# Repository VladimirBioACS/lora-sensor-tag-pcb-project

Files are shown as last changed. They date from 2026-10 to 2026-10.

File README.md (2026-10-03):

# LoRa Sensor TAG

Simple LoRa humidity and temperature monitoring device, based on the ESP32-Wroom-D SoC module.
Repo contains KiCAD 10 project for LoRa Sensor TAG device with external component libs.

## Project description

The architecture of the project is described with the diagram below (lora_sensor_tag_architecture.jpg):

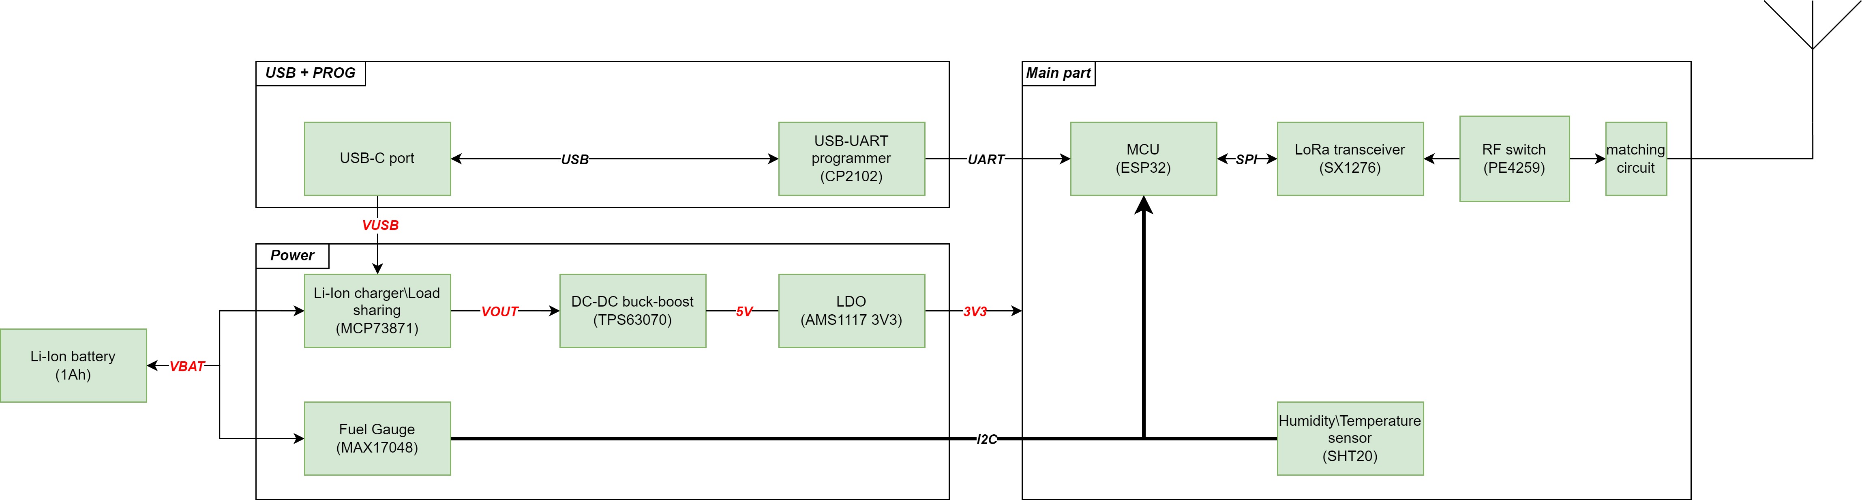
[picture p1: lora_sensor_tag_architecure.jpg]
project architecure


The LoRa Sensor Project is designed to create a network of low-power, long-range sensors for environmental monitoring. 
The project aims to leverage LoRa technology to enable efficient data collection from remote locations, 
providing real-time insights into various environmental parameters such as temperature and humidity. The LoRa modem works
within 433 Mhz LF baseband.

It is developed simply for the educational purpose, aiming to provide students and hobbyists with hands-on experience in 
building and managing a LoRa-based sensor network.

The device composed of several key components:

- A LoRa module for long-range wireless communication.
- Sensor for measuring environmental parameters such as temperature and humidity.
- A microcontroller to process sensor data and manage communication.
- A power source (li-ion battery) with DC-DC buck-boost converter and LDO to manage power supply and ensure stable operation.
- Auxiliary components such as USB-UART bridge for serial communication and programming the microcontroller.

The following key components were used:

- MAX17048G_T10 - Fuel Gauge IC to monitor battery status
- MCP73871-2CAI_ML - Li-Ion/Li-Polymer Battery Charger to manage battery charging and protection
- SHT20 - Temperature and Humidity Sensor to measure environmental conditions
- SX1276IMLTRT - LoRa Transceiver Module to enable long-range wireless communication
- PE4259 - RF switch for LoRa antenna
- TPS63070RNMR - Buck-Boost Converter to manage power supply and ensure stable operation
- ESP32 - Microcontroller to process sensor data and manage communication
- CP2102 - USB to UART Bridge Controller to enable serial communication between the microcontroller and a computer. Also, acts as a programmer for the microcontroller.

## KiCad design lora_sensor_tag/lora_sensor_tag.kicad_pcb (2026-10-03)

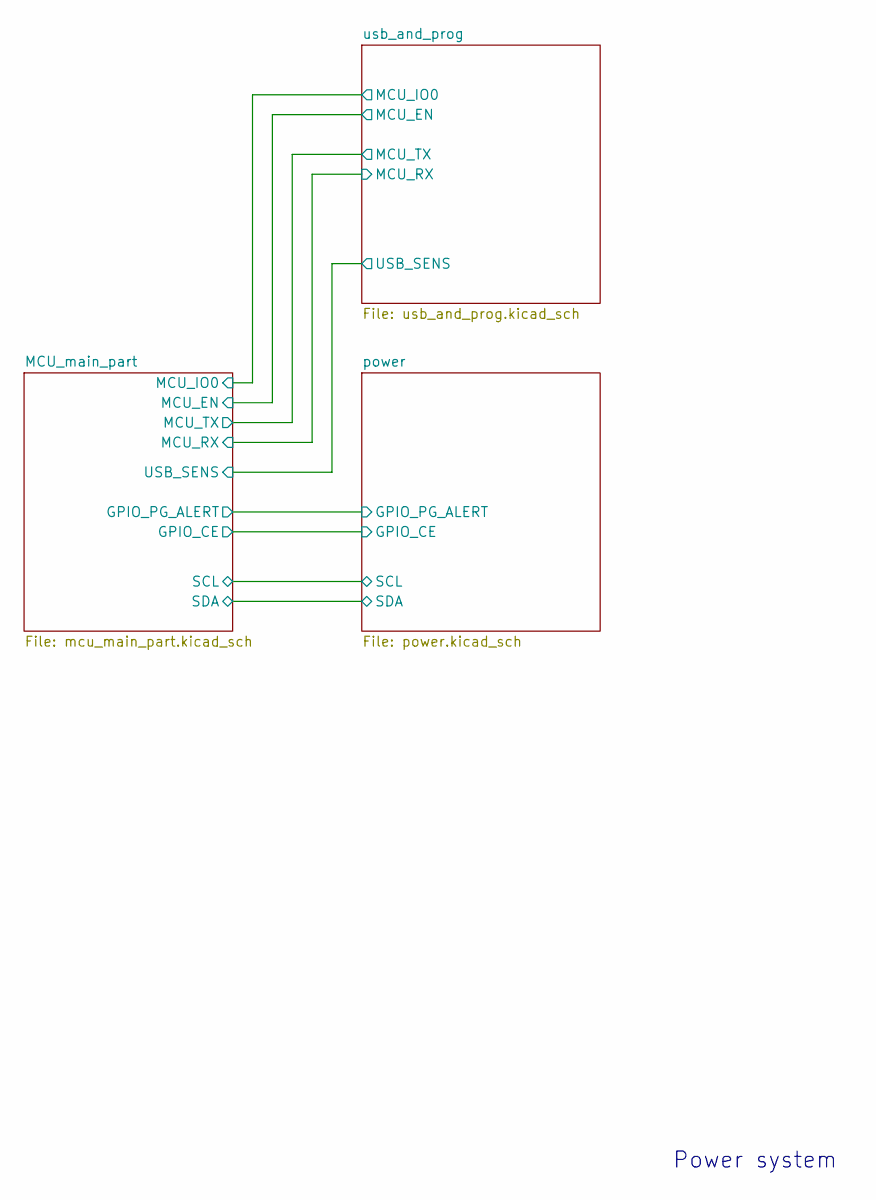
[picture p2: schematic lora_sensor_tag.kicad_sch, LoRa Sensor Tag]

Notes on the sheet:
Power system

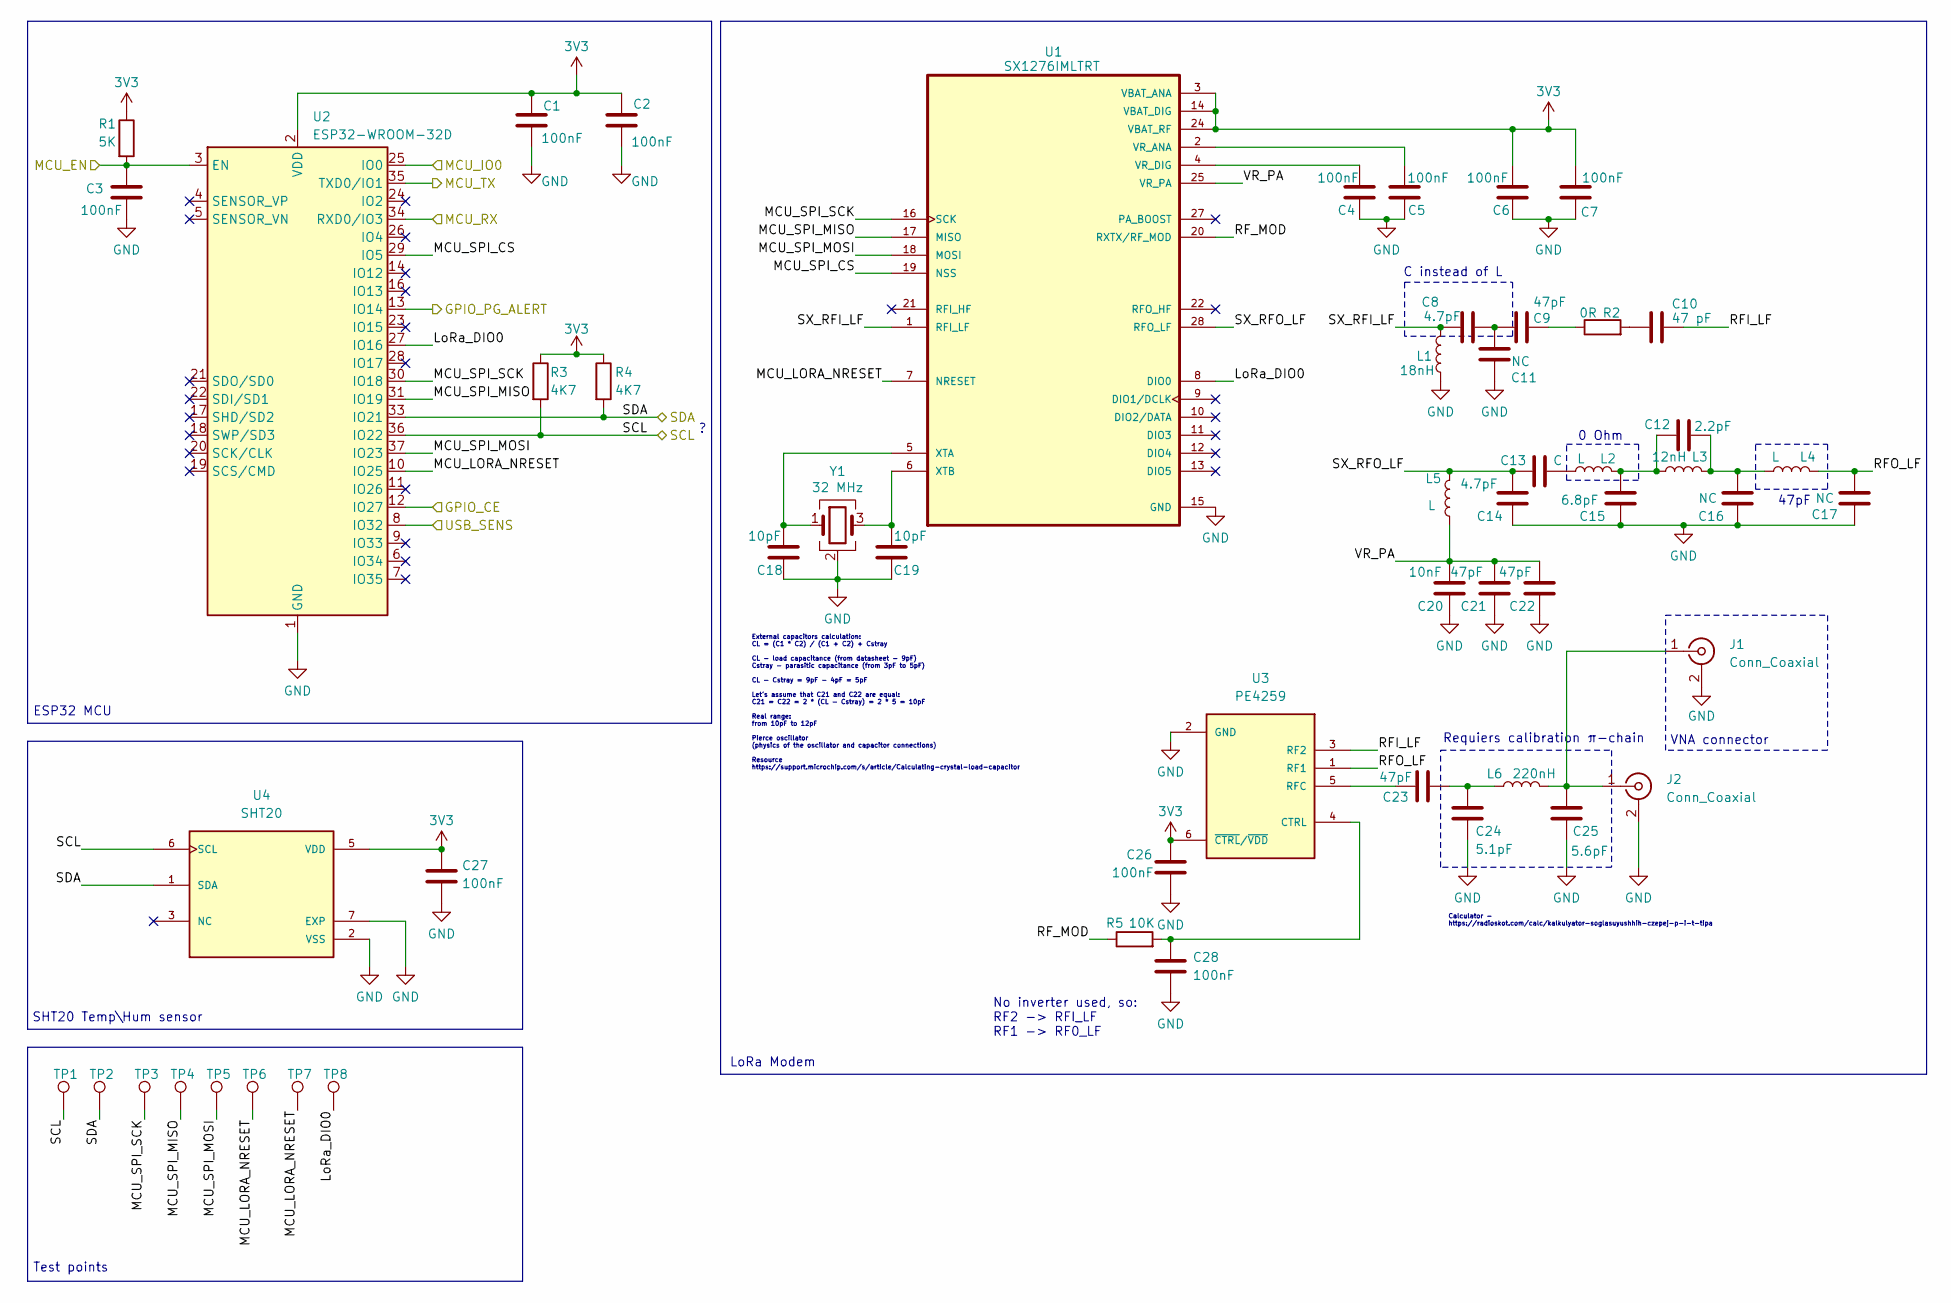
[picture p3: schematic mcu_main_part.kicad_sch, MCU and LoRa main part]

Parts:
C1, C2, C3, C4, C5, C6, C7, C26, C27, C28: 100nF; C_0603_1608Metric
C8, C14: 4.7pF; C_0402_1005Metric
C9, C21, C22, C23: 47pF; C_0402_1005Metric
C10: 47 pF; C_0402_1005Metric
C11, C16, C17: NC; C_0402_1005Metric
C12: 2.2pF; C_0402_1005Metric
C13: C; C_0402_1005Metric
C15: 6.8pF; C_0402_1005Metric
C18, C19: 10pF; C_0603_1608Metric
C20: 10nF; C_0402_1005Metric
C24: 5.1pF; C_0402_1005Metric
C25: 5.6pF; C_0402_1005Metric
J1, J2: Conn_Coaxial; SMA_BAT_Wireless_BWSMA-KWE-Z001
L1: 18nH; L_0402_1005Metric
L2: L; R_0402_1005Metric
L3: 12nH; L_0402_1005Metric
L4: L; C_0402_1005Metric
L5: L; L_0402_1005Metric
L6: 220nH; L_0402_1005Metric
R1: 5K; R_0603_1608Metric
R2: 0R; VREG_TPS63070RNMR
R3, R4: 4K7; R_0603_1608Metric
R5: 10K; R_0603_1608Metric
TP1, TP2, TP3, TP4, TP5, TP6, TP7, TP8: TestPoint; TestPoint_Pad_D1.0mm
U1: SX1276IMLTRT; QFN65P600X600X100-29N; PARTREV 5
U2: ESP32-WROOM-32D
U3: PE4259; SOT65P215X110-6N
U4: SHT20; XDCR_SHT20; PARTREV 4
Y1: 32 MHz; Crystal_SMD_3225-4Pin_3.2x2.5mm

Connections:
3V3: C1.1, C2.1, C6.1, C7.1, C26.1, C27.1, R1.1, R3.1, R4.1, U1.3 (VBAT_ANA), U1.14 (VBAT_DIG), U1.24 (VBAT_RF), U2.2 (VDD), U3.6 (~CTRL/~VDD), U4.5 (VDD); also elsewhere on the board
/MCU_main_part/GPIO_CE: U2.12 (IO27); also elsewhere on the board
/MCU_main_part/GPIO_PG_ALERT: U2.13 (IO14); also elsewhere on the board
/MCU_main_part/LoRa_DIO0: TP8.1 (1_1), U1.8 (DIO0), U2.27 (IO16)
/MCU_main_part/MCU_EN: C3.1, R1.2, U2.3 (EN); also elsewhere on the board
/MCU_main_part/MCU_IO0: U2.25 (IO0); also elsewhere on the board
/MCU_main_part/MCU_LORA_NRESET: TP6.1 (1_1), TP7.1 (1_1), U1.7 (NRESET), U2.10 (IO25)
/MCU_main_part/MCU_RX: U2.34 (RXD0/IO3); also elsewhere on the board
/MCU_main_part/MCU_SPI_CS: U1.19 (NSS), U2.29 (IO5)
/MCU_main_part/MCU_SPI_MISO: TP4.1 (1_1), U1.17 (MISO), U2.31 (IO19)
/MCU_main_part/MCU_SPI_MOSI: TP5.1 (1_1), U1.18 (MOSI), U2.37 (IO23)
/MCU_main_part/MCU_SPI_SCK: TP3.1 (1_1), U1.16 (SCK), U2.30 (IO18)
/MCU_main_part/MCU_TX: U2.35 (TXD0/IO1); also elsewhere on the board
/MCU_main_part/RFI_LF: C10.2, U3.3 (RF2)
/MCU_main_part/RFO_LF: C17.1, L4.2, U3.1 (RF1)
/MCU_main_part/RF_MOD: R5.1, U1.20 (RXTX/RF_MOD)
/MCU_main_part/SCL: R3.2, TP1.1 (1_1), U2.36 (IO22), U4.6 (SCL); also elsewhere on the board
/MCU_main_part/SDA: R4.2, TP2.1 (1_1), U2.33 (IO21), U4.1 (SDA); also elsewhere on the board
/MCU_main_part/SX_RFI_LF: C8.1, L1.2, U1.1 (RFI_LF)
/MCU_main_part/SX_RFO_LF: C13.2, C14.1, L5.2, U1.28 (RFO_LF)
/MCU_main_part/USB_SENS: U2.8 (IO32); also elsewhere on the board
/MCU_main_part/VR_PA: C20.1, C21.1, C22.1, L5.1, U1.25 (VR_PA)
GND: C1.2, C2.2, C3.2, C4.2, C5.2, C6.2, C7.2, C11.2, C14.2, C15.2, C16.2, C17.2, C18.2, C19.2, C20.2, C21.2, C22.2, C24.1, C25.1, C26.2, C27.2, C28.1, J1.2 (Ext), J2.2 (Ext), L1.1, U1.15 (GND), U1.23 (GND), U1.26 (GND), U1.29 (GND), U2.1 (GND), U2.15 (GND), U2.38 (GND), U2.39 (GND), U3.2 (GND), U4.2 (VSS), U4.7 (EXP), Y1.2 (G), Y1.4 (G); also elsewhere on the board
unnamed: C9.2, R2.1
unnamed: C10.1, R2.2
unnamed: C8.2, C9.1, C11.1
unnamed: C12.1, C16.1, L3.2, L4.1
unnamed: C12.2, C15.1, L2.2, L3.1
unnamed: C13.1, L2.1
unnamed: C23.2, C24.2, L6.1
unnamed: C25.2, J1.1 (In), J2.1 (In), L6.2
unnamed: C5.1, U1.2 (VR_ANA)
unnamed: C4.1, U1.4 (VR_DIG)
unnamed: C18.1, U1.5 (XTA), Y1.1
unnamed: C19.1, U1.6 (XTB), Y1.3
unnamed: C28.2, R5.2, U3.4 (CTRL)
unnamed: C23.1, U3.5 (RFC)

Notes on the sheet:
SHT20 Temp\Hum sensor
External capacitors calculation: CL = (C1 * C2) / (C1 + C2) + Cstray CL - load capacitance (from datasheet - 9pF) Cstray - parasitic capacitance (from 3pF to 5pF) CL - Cstray = 9pF - 4pF = 5pF Let's assume that C21 and C22 are equal: C21 = C22 = 2 * (CL - Cstray) = 2 * 5 = 10pF Real range: from 10p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
Requiers calibration π-chain
Test points
LoRa Modem
ESP32 MCU
0 Ohm
47pF
VNA connector
C instead of L
Calculator - https://radioskot.com/calc/kalkulyator-soglasuyushhih-czepej-p-i-t-tipa
No inverter used, so: RF2 -> RFI_LF RF1 -> RF0_LF

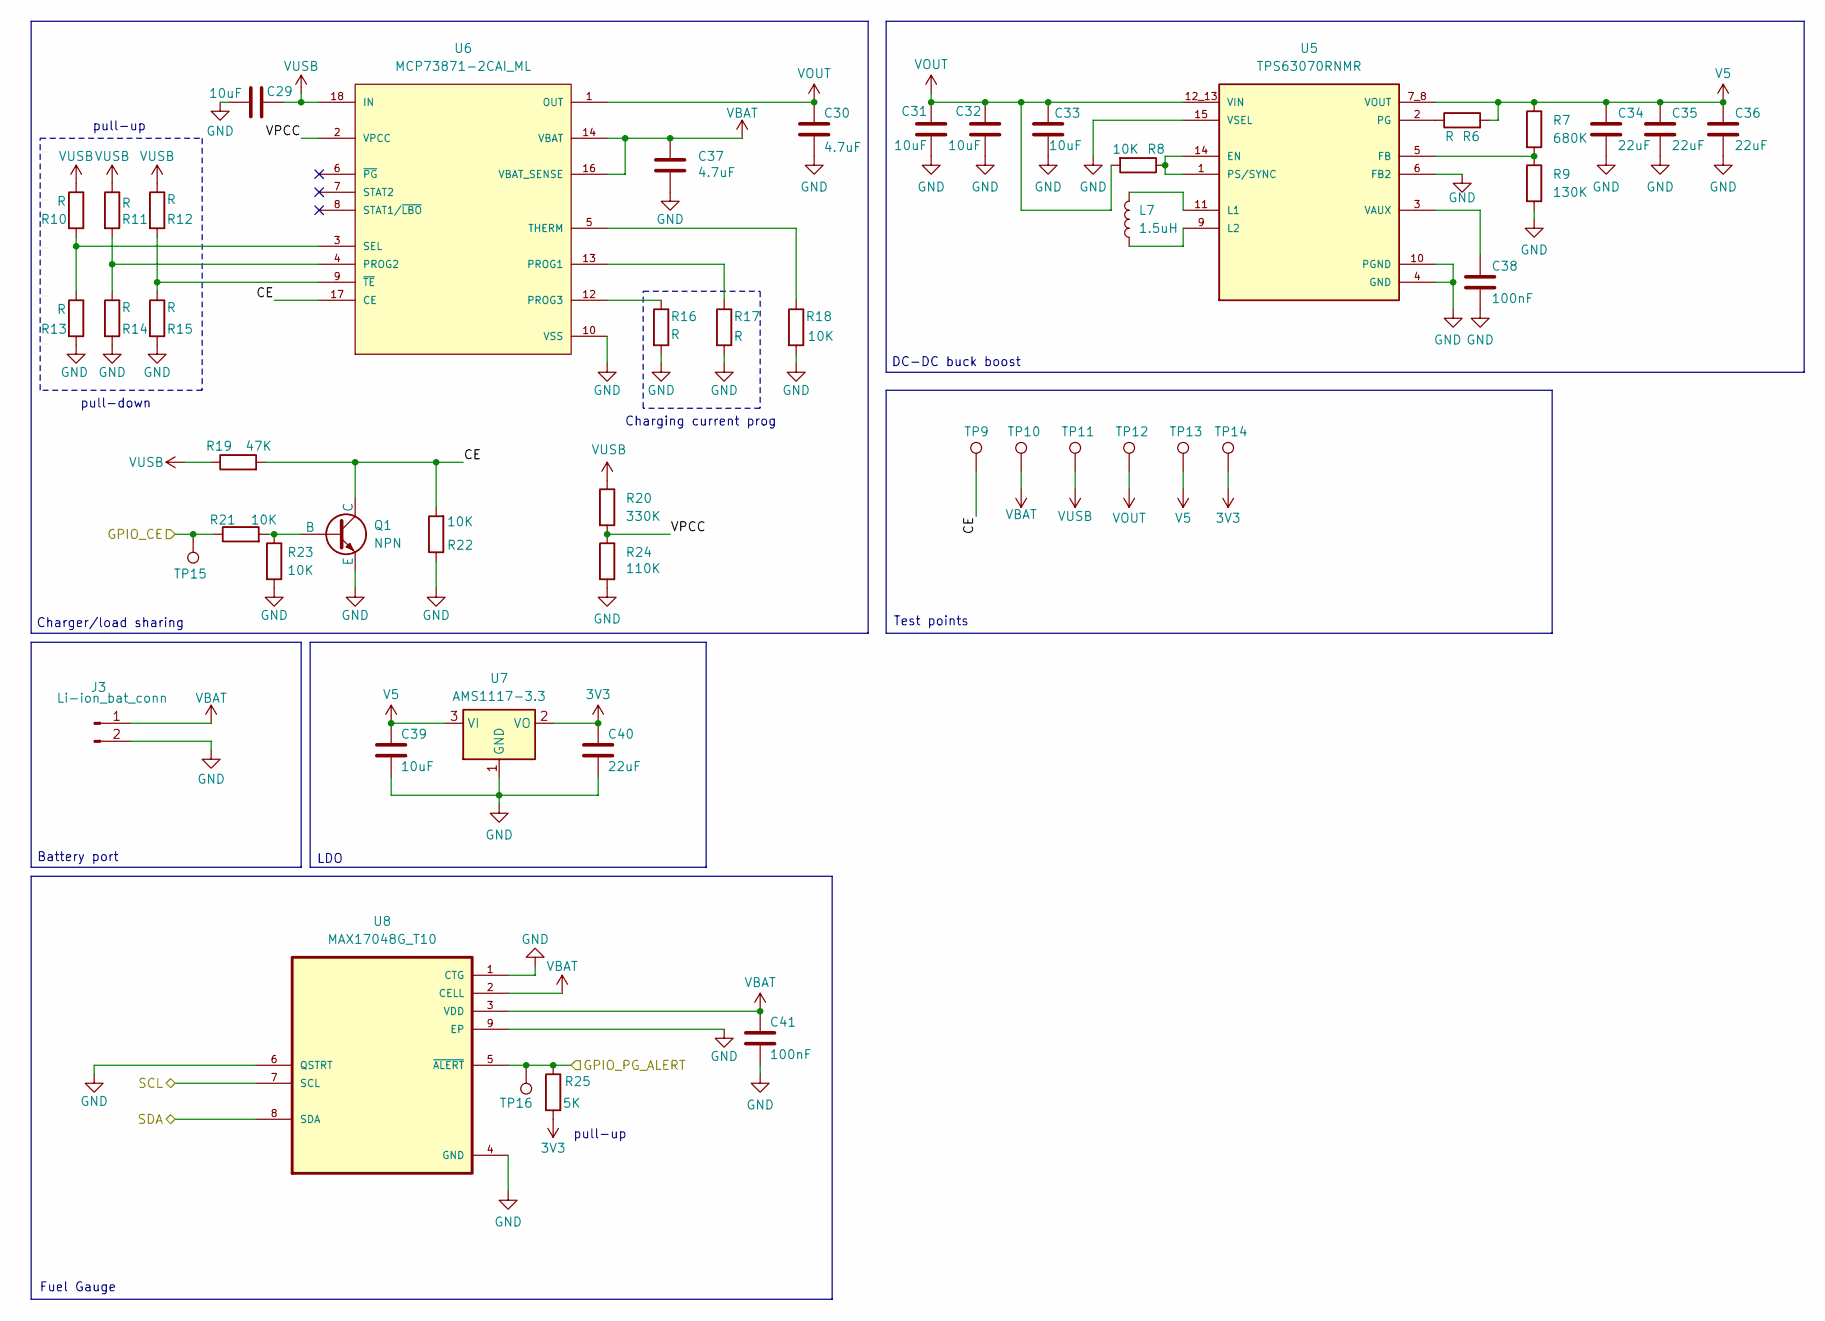
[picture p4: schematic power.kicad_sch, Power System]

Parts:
C29, C33, C39: 10uF; C_0603_1608Metric
C30, C37: 4.7uF; C_0603_1608Metric
C31, C32: 10uF; C_0805_2012Metric
C34, C35, C36: 22uF; C_0805_2012Metric
C38, C41: 100nF; C_0603_1608Metric
C40: 22uF; C_0603_1608Metric
J3: Li-ion_bat_conn; PinHeader_1x02_P2.54mm_Vertical
L7: 1.5uH; L_Coilcraft_XxL4040
Q1: NPN; SOT-23
R6, R10, R11, R12, R13, R14, R15, R16, R17: R; R_0603_1608Metric
R7: 680K; R_0603_1608Metric
R8, R18, R21, R22, R23: 10K; R_0603_1608Metric
R9: 130K; R_0603_1608Metric
R19: 47K; R_0603_1608Metric
R20: 330K; R_0603_1608Metric
R24: 110K; R_0603_1608Metric
R25: 5K; R_0603_1608Metric
TP9, TP10, TP11, TP12, TP13, TP14, TP15, TP16: TestPoint; TestPoint_Pad_D1.0mm
U5: TPS63070RNMR; VREG_TPS63070RNMR; PARTREV B
U6: MCP73871-2CAI_ML; QFN50P400X400X100-21N; PARTREV D
U7: AMS1117-3.3; SOT-223-3_TabPin2
U8: MAX17048G_T10; SON50P200X200X80-9N

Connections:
3V3: C40.1, R25.2, TP14.1 (1_1), U7.2 (VO); also elsewhere on the board
/MCU_main_part/GPIO_CE: R21.1, TP15.1 (1_1); also elsewhere on the board
/MCU_main_part/GPIO_PG_ALERT: R25.1, TP16.1 (1_1), U8.5 (~ALERT); also elsewhere on the board
/MCU_main_part/SCL: U8.7 (SCL); also elsewhere on the board
/MCU_main_part/SDA: U8.8 (SDA); also elsewhere on the board
/power/CE: Q1.1 (C), R19.2, R22.2, TP9.1 (1_1), U6.17 (CE)
/power/VPCC: R20.2, R24.1, U6.2 (VPCC)
GND: C29.1, C30.2, C31.2, C32.2, C33.2, C34.2, C35.2, C36.2, C37.2, C38.2, C39.2, C40.2, C41.2, J3.2, Q1.3 (E), R9.2, R13.2, R14.2, R15.2, R16.2, R17.2, R18.2, R22.1, R23.2, R24.2, U5.4 (GND), U5.6 (FB2), U5.10 (PGND), U5.15 (VSEL), U6.10 (VSS), U6.11 (VSS), U6.21 (VSS), U7.1 (GND), U8.1 (CTG), U8.4 (GND), U8.6 (QSTRT), U8.9 (EP); also elsewhere on the board
unnamed: Q1.2 (B), R21.2, R23.1
unnamed: R8.1, U5.1 (PS/SYNC), U5.14 (EN)
unnamed: R7.2, R9.1, U5.5 (FB)
unnamed: L7.2, U5.11 (L1)
unnamed: L7.1, U5.9 (L2)
unnamed: R6.1, U5.2 (PG)
unnamed: C38.1, U5.3 (VAUX)
unnamed: R17.1, U6.13 (PROG1)
unnamed: R11.2, R14.1, U6.4 (PROG2)
unnamed: R16.1, U6.12 (PROG3)
unnamed: R10.2, R13.1, U6.3 (SEL)
unnamed: R18.1, U6.5 (THERM)
unnamed: R12.2, R15.1, U6.9 (~TE)
V5: C34.1, C35.1, C36.1, C39.1, R6.2, R7.1, TP13.1 (1_1), U5.7_8 (VOUT), U7.3 (VI)
VBAT: C37.1, C41.1, J3.1, TP10.1 (1_1), U6.14 (VBAT), U6.15 (VBAT), U6.16 (VBAT_SENSE), U8.2 (CELL), U8.3 (VDD)
VOUT: C30.1, C31.1, C32.1, C33.1, R8.2, TP12.1 (1_1), U5.12_13 (VIN), U6.1 (OUT), U6.20 (OUT)
VUSB: C29.2, R10.1, R11.1, R12.1, R19.1, R20.1, TP11.1 (1_1), U6.18 (IN), U6.19 (IN); also elsewhere on the board

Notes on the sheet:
Charging current prog
pull-down
DC-DC buck boost
pull-up
LDO
Test points
Charger/load sharing
Battery port
Fuel Gauge

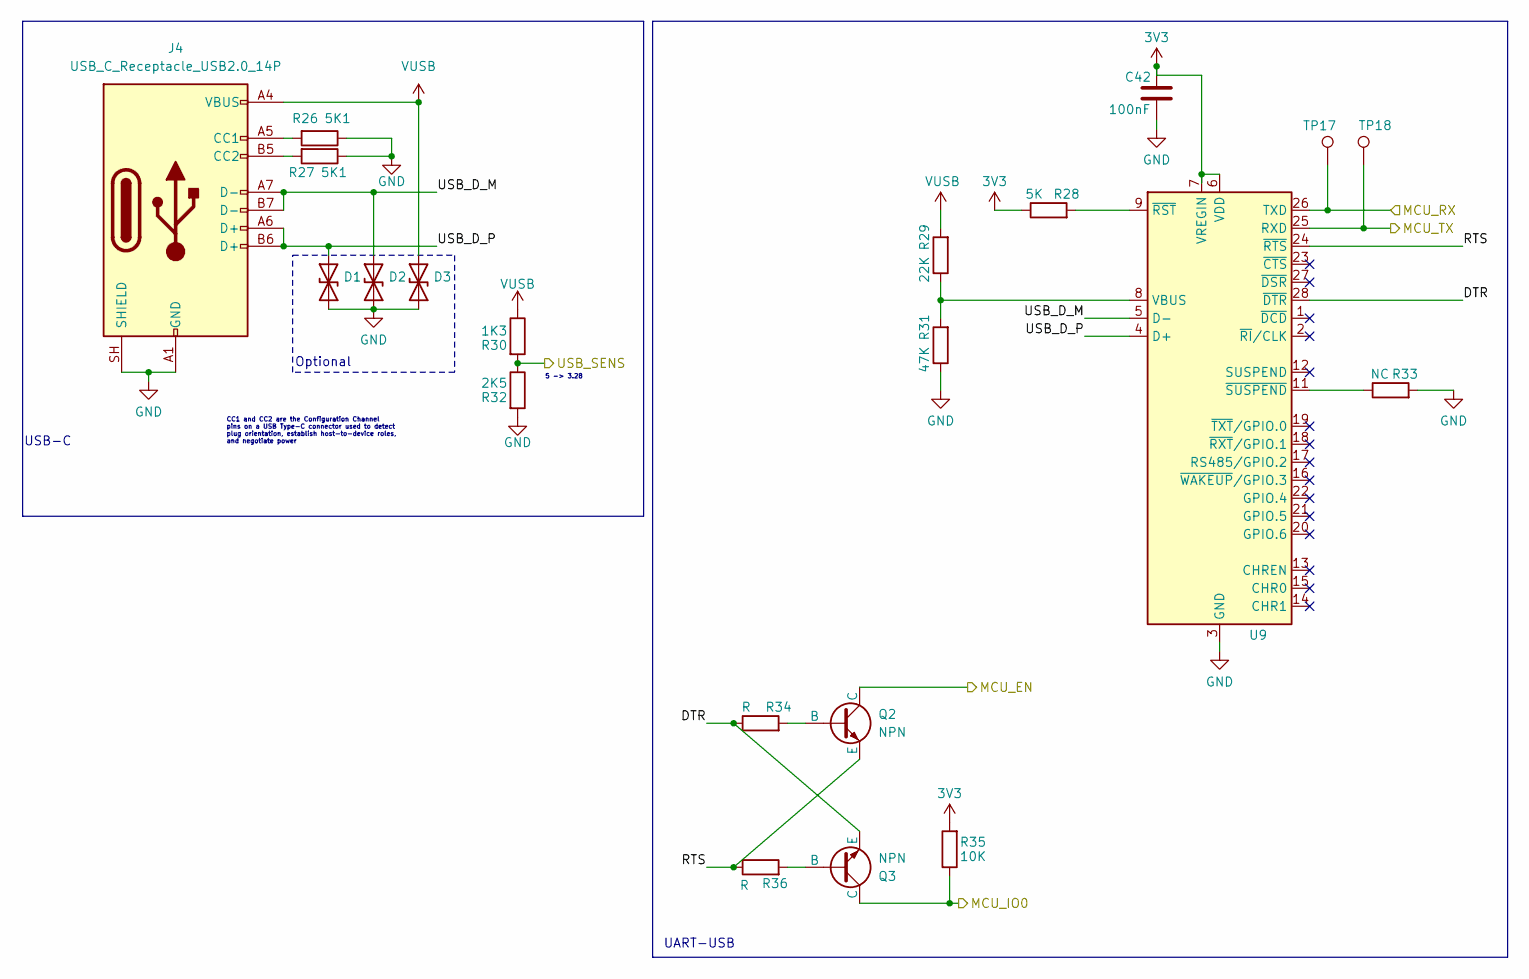
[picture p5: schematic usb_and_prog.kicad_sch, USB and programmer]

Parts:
C42: 100nF; C_0603_1608Metric
D1, D2, D3: 1N630xCA; D_0603_1608Metric
J4: USB_C_Receptacle_USB2.0_14P; USB_C_Receptacle_XKB_U262-16XN-4BVC11
Q2, Q3: NPN; SOT-23
R26, R27: 5K1; R_0603_1608Metric
R28: 5K; R_0603_1608Metric
R29: 22K; R_0603_1608Metric
R30: 1K3; R_0603_1608Metric
R31: 47K; R_0603_1608Metric
R32: 2K5; R_0603_1608Metric
R33: NC; R_0603_1608Metric
R34, R36: R; R_0603_1608Metric
R35: 10K; R_0603_1608Metric
TP17, TP18: TestPoint; TestPoint_Pad_D1.0mm
U9: CP2102N-Axx-xQFN28; QFN-28-1EP_5x5mm_P0.5mm_EP3.35x3.35mm

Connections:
3V3: C42.1, R28.1, R35.2, U9.6 (VDD), U9.7 (VREGIN); also elsewhere on the board
/MCU_main_part/MCU_EN: Q2.1 (C); also elsewhere on the board
/MCU_main_part/MCU_IO0: Q3.1 (C), R35.1; also elsewhere on the board
/MCU_main_part/MCU_RX: TP17.1 (1_1), U9.26 (TXD); also elsewhere on the board
/MCU_main_part/MCU_TX: TP18.1 (1_1), U9.25 (RXD); also elsewhere on the board
/MCU_main_part/USB_SENS: R30.2, R32.1; also elsewhere on the board
/usb_and_prog/DTR: Q3.3 (E), R34.1, U9.28 (~DTR)
/usb_and_prog/RTS: Q2.3 (E), R36.1, U9.24 (~RTS)
/usb_and_prog/USB_D_M: D2.2 (A2), J4.A7 (D-), J4.B7 (D-), U9.5 (D-)
/usb_and_prog/USB_D_P: D1.2 (A2), J4.A6 (D+), J4.B6 (D+), U9.4 (D+)
GND: C42.2, D1.1 (A1), D2.1 (A1), D3.1 (A1), J4.A1 (GND), J4.A12 (GND), J4.B1 (GND), J4.B12 (GND), J4.SH (SHIELD), R26.1, R27.1, R31.1, R32.2, R33.2, U9.3 (GND), U9.29 (GND); also elsewhere on the board
unnamed: J4.A5 (CC1), R26.2
unnamed: J4.B5 (CC2), R27.2
unnamed: Q2.2 (B), R34.2
unnamed: Q3.2 (B), R36.2
unnamed: R29.1, R31.2, U9.8 (VBUS)
unnamed: R28.2, U9.9 (~RST)
unnamed: R33.1, U9.11 (~SUSPEND)
VUSB: D3.2 (A2), J4.A4 (VBUS), J4.A9 (VBUS), J4.B4 (VBUS), J4.B9 (VBUS), R29.2, R30.1; also elsewhere on the board

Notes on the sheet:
USB-C
5 -> 3.28
Optional
UART-USB
CC1 and CC2 are the Configuration Channel pins on a USB Type-C connector used to detect plug orientation, establish host-to-device roles, and negotiate power

Board: 2 copper layers, 123 parts (0 on the bottom side), 67 nets, no tracks yet.

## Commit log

2026-09-27 libs: Add 3d-party component libs to project
    Adds the following 3d-party component libraries to the project:
    - MAX17048G_T10 - Fuel Gauge IC
    - MCP73871-2CAI_ML - Li-Ion/Li-Polymer Battery Charger
    - SHT20 - Temperature and Humidity Sensor
    - SX1276IMLTRT - LoRa Transceiver Module
    - TPS63070RNMR - Buck-Boost Converter
2026-09-27 Add initial KiCAD project
    [lora_sensor_tag.kicad_pcb, lora_sensor_tag.kicad_sch]
2026-09-27 lora_tag_sensor: Add shematic design
    The shematic design for the following components has been added:
    - MCU main part (ESP32 part)
    - Power supply (completed)
    [lora_sensor_tag.kicad_sch, mcu_main_part.kicad_sch, power.kicad_sch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]
2026-09-30 libs: Add PE4259 RF switch lib
2026-09-30 lora_sensor_tag: Update shematic
    Update schematic with the following changes:
    - Add SX1276 LoRa modem schematic;
    - Add antenna matching network for SX1276 LoRa modem;
    - Add PE4259 RF switch for SX1276 LoRa modem;
    - Add USB-C connector;
    - Add CP2102 USB-to-UART bridge and programming interface;
    [lora_sensor_tag.kicad_sch, mcu_main_part.kicad_sch, power.kicad_sch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]
2026-10-03 Update schematic notation and fix bugs
    Global labels notation updated;
    Swapped line order in schematic fixed;
    Added pull-up resistor to PG-ALERT pin (fuel gauge)
    [lora_sensor_tag.kicad_sch, mcu_main_part.kicad_sch, power.kicad_sch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]
2026-10-03 Bug fixing
    The following bugs and issues have been fixed:
    - Fixed LoRa Rx\Tx line polarity;
    - Removed unnneccessary pull-up\pull-down resistors;
    - Added pull-up resistor to IO0;
    - Added resistive divider for MCP7387 VPCC pin;
    - GPIO_SEL moved from IO4 to IO26 (IO4 used for flash init and can cause unexpected behavior);
    - CC1 and CC2 of USB-C port connected to GND via pull-down resistors;
    [mcu_main_part.kicad_sch, power.kicad_sch, usb_and_prog.kicad_sch]
2026-10-03 Update Charge Enable mechanism on MCP73871
    Adds the following charge enable control mechanism
    on MCP73871:
    VUSB ──|>|──┐
    D_CE1 │
    ├── V_CE_SRC ── R17 ──┬──── CE, U6.17
    VBAT ──|>|──┘ 47 кОм │ |
    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
    [lora_sensor_tag.kicad_sch, mcu_main_part.kicad_sch, power.kicad_sch]
2026-10-03 Large schematic update
    This commit update the following:
    - Update MCP73871 CE control schematic
    - Finished schematic development and footprint
    assignment
    [lora_sensor_tag.kicad_pcb, lora_sensor_tag.kicad_sch, mcu_main_part.kicad_sch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]
2026-10-11 Update schematics
    Adds the following updates to the schematics:
    - Add power switch to the device;
    - Add various LED indicators for device status monitoring;
    - Add Reset and Prog buttons for device control;
2026-10-11 Update PCB routing rules
2026-10-11 pcb_layout: Add initial board layout
    Adds:
    - Initial board dimensions;
    - Initial MCU component placement and routing
2026-10-17 Add custom Wi-Fi sign silkscreen footprint
2026-10-17 Update PCB layout routing
    Updates and adds the following changes to the PCB
    layout routing:
    - Changed board dimensions and topology;
    - Add layout for MCP73871 Li-ion battery charger;
    - Add layout for MAX17048 Fuel Gauge;
2026-10-24 DC-DC buckboost to 3V3 using TPS63070. minor fixes to TPS63070 schema.
